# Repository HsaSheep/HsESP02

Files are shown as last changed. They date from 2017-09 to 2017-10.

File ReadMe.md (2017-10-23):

[schema](ESP-WROOM-02_BreakOut)

## About repo. ##

This repository converts "ESP-WROOM-02" module to 2.54 mm pitch.  
I am assuming to use on a solderless breadboard.

---
## Board's ##

#### V4 ####

Memo : V4はサンプル画像と作者の実物でいくつかの変更点が含まれていますが、回路な変更はありません。<br>
　　　　Sillk等にいくつかの軽微な修正が含まれています。また、それに伴いBuildDataが更新されています。

<table>
    <tr>
        <td>
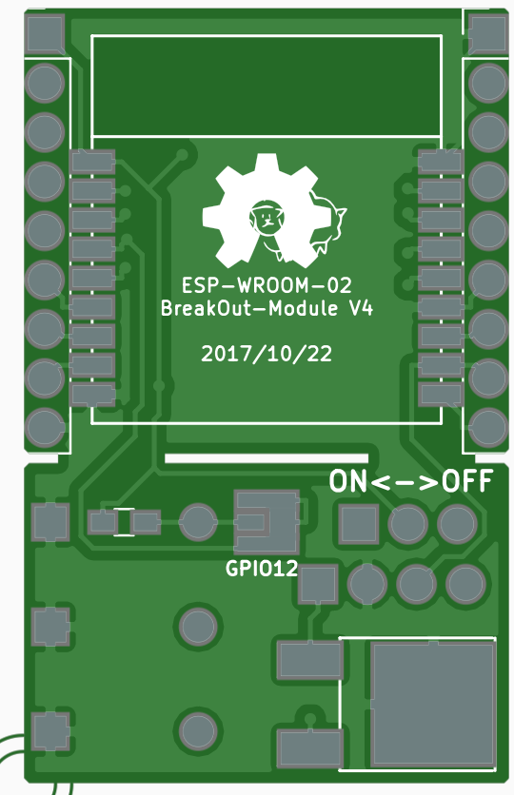
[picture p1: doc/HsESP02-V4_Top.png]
            
        </td>
        <td>
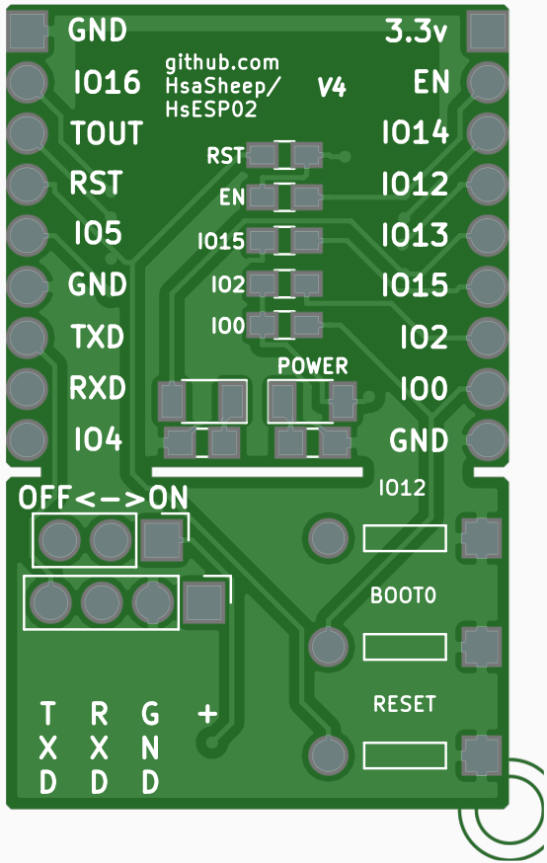
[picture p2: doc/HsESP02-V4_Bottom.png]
Bottom View(image)
            
        </td>
    </tr>
</table>

<!--
[schema]
-->

---

<details>
<summary>Old Version...</summary>

#### V3 ####

<table>
    <tr>
        <td>
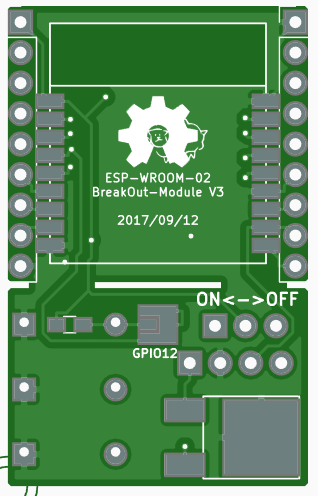
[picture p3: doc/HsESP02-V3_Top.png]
            
        </td>
        <td>
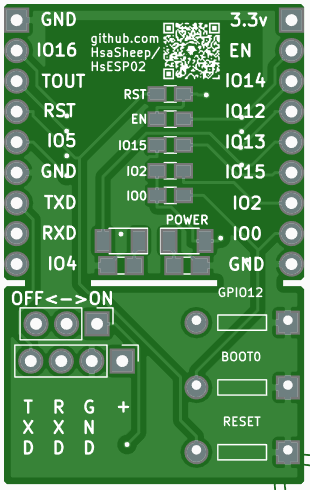
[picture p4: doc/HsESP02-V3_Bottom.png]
Bottom View(image)
            
        </td>
    </tr>
</table>

<!--
[schema]
-->

---

#### V2 ####

<table>
    <tr>
        <td>
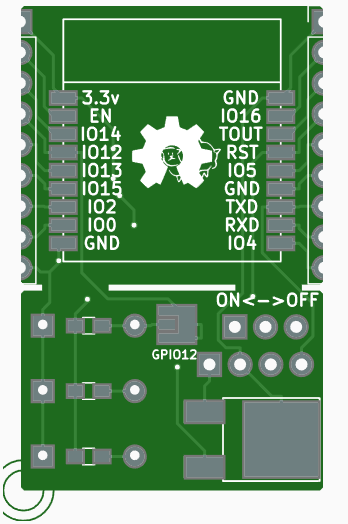
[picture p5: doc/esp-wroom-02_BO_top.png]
            
        </td>
        <td>
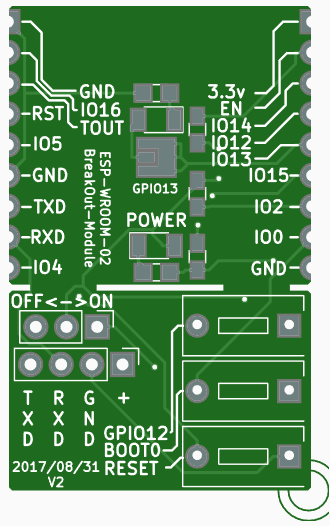
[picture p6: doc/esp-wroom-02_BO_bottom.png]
Bottom View(image)
            
        </td>
    </tr>
</table>

<!--
[schema]
-->

</details>

---

## This Repo... Empty??? ##
  
~~I am currently manufacturing the board.~~
~~All files are added as soon as normal operation can be confirmed.~~

~~(I am waiting for luggage from Elecrow.)~~

## 疲れたので日本語で追記します。 ##

Elecrowが中国の１０月の国のお休み的なやつ（国慶節）から帰ってきてくれたので
、頼んでいた基板が（かなり遅れて）到着し、現品を確認できました。

<table>
    <tr>
        <td>
            基板(右側)(image)
        </td>
        <td>
            実装した(image)
        </td>
    </tr>
</table>

難しい部分を極力省いて、比較的小型で最小限の機能のブレークアウト基板を開発することが目的でしたので、
回路的に動作しない等のエラーはありませんでした。
そもそもAutoRoutingも使ってるので、失敗する要素が少ないんですが、やっぱり不安でして。

今回の目標であった、
* Reset、Boot0 および ユーザスイッチ1個を実装する。
* 全てハード的にプルアップする(マイコンでプルアップダウンをしない)。
* ブレッドボードに直接刺せる幅で、なおかつ左右に1列ずつ余るようにする。
* 組み込んだりする際の為に、SWや書き込み端子部分を切り離せるようにする。

今回の製作で目標はとりあえず達成できたと思われるので、
設計データ等をバックアップも兼ねてアップロードして置きます。

利用は自由ですし、改変も問題ないと思います。むしろ、自分も他人様のライブラリを引っ張ってきて作っている身です。

もし、Elecrow等にガーバーぶん投げるついでに、BreakOut基板も投げたいけど作るのだるいなーって感じだった時は、一応、このデータで作れているので一緒に出すと現時点では5枚600~700円程度で作れますので割と安価だと思います。

~~もっとよくできたのが転がってそうな気がしますが…~~

ガーバーデータはKiCadフォルダ内のG_Silks_v*.zipです。基本的に数字は製作した順ですので、複数ある場合は最新を見てもらえると良いかと。
いらなくなったら最新残して消します。

一方、プロジェクトファイル自体はそのまま更新しています。内部的にはzipを弾いてGit管理しているので…。

あ、あと、世間がWiFiのセキュリティで騒いでいますね。クラックとかなんとか…
FWのアップデートがあるようなので、組み立て後にアップデートして見るのも良いかと。

その際だけはWindowsマシンがあると楽かもしれません…(実体験)

##  ファイルについて ##

* KiCad
> Kicadフォルダ内にはKiCadにて設計した基板のデータ等が入っています。

* Arduino
> Arduinoフォルダ内には基板組み立て後にLED,およびWiFi,と適当なピン(デフォルトではbeep_pinとして5ピンを指定しています)をテストするためのスケッチです。ほとんどがESP8226のHttpServerのスケッチ例そのままですが、beep_pinの名の通り、圧電スピーカを接続し、状況を音で知らせたり、MACアドレス制限(を、していて不便だったので、制限)をしている場合のためにMACアドレスを表示するようになっています。SSIDとPassWordをそれぞれ自分のWiFiものに書き換えて制作したボードに書き込み、テストしてみてください。(APとして動作するように書き換えてもいいかもしれませんね。自分はネットに接続したまま使用したいのでこのような仕様となっています。)

<details>
<summary>スケッチの使い方...</summary>

>> OTA(Over The Air 無線LAN経由によるUpdate )を使用してみたい場合
>> 1. Boot0スイッチを使用して起動しシリアル接続にてHsESP02_BasicOTA.inoを書き込んでください。
>> 1. その後、スケッチを書き込みする際にはBasicOTAに追記する形で作成し、ArduinoIDE上のシリアルポートにてネットワークポートに表示されるOTA用ポートを指定して ***Boot0スイッチ等でブートモードに入ったりはせずに*** Uploadをしてください。
>> 1. (今後はHsESP02_BasicOTA.inoやその元になっているBasicOTA.ino等にアップデートがない限り、１を実行する必要はありません。)

>> OTAを使用しない場合
>> 1. Boot0スイッチを使用して起動しシリアル接続にてHsESP02_ESP-WROOM-02_Test.inoを書き込んで動作を確認します。

</details>

##### 念のため #####
何かあっても責任はとりません。
ご自身の判断のもと行ってください。

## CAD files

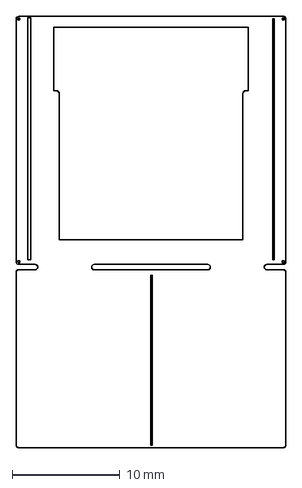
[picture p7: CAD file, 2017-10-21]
KiCad/dxf/ESP-WROOM-02_2.dxf
25.0 x 40.0 mm

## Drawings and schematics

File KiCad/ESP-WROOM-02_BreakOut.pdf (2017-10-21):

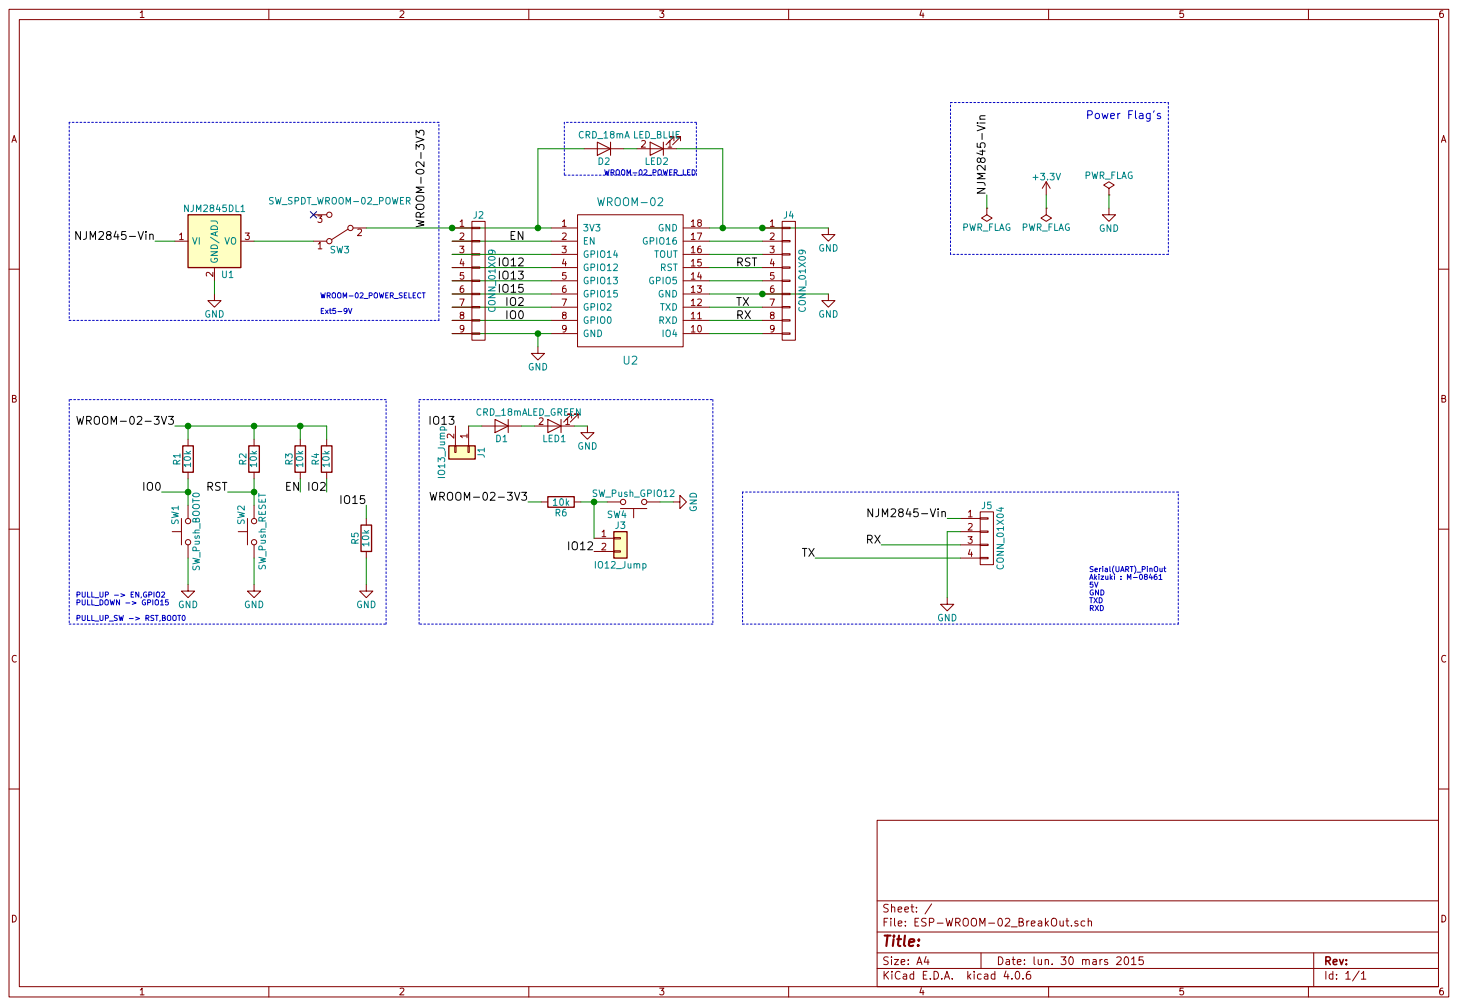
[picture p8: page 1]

File: ESP-WROOM-02_BreakOut.sch Sheet: /
Id: 1/1 Title:

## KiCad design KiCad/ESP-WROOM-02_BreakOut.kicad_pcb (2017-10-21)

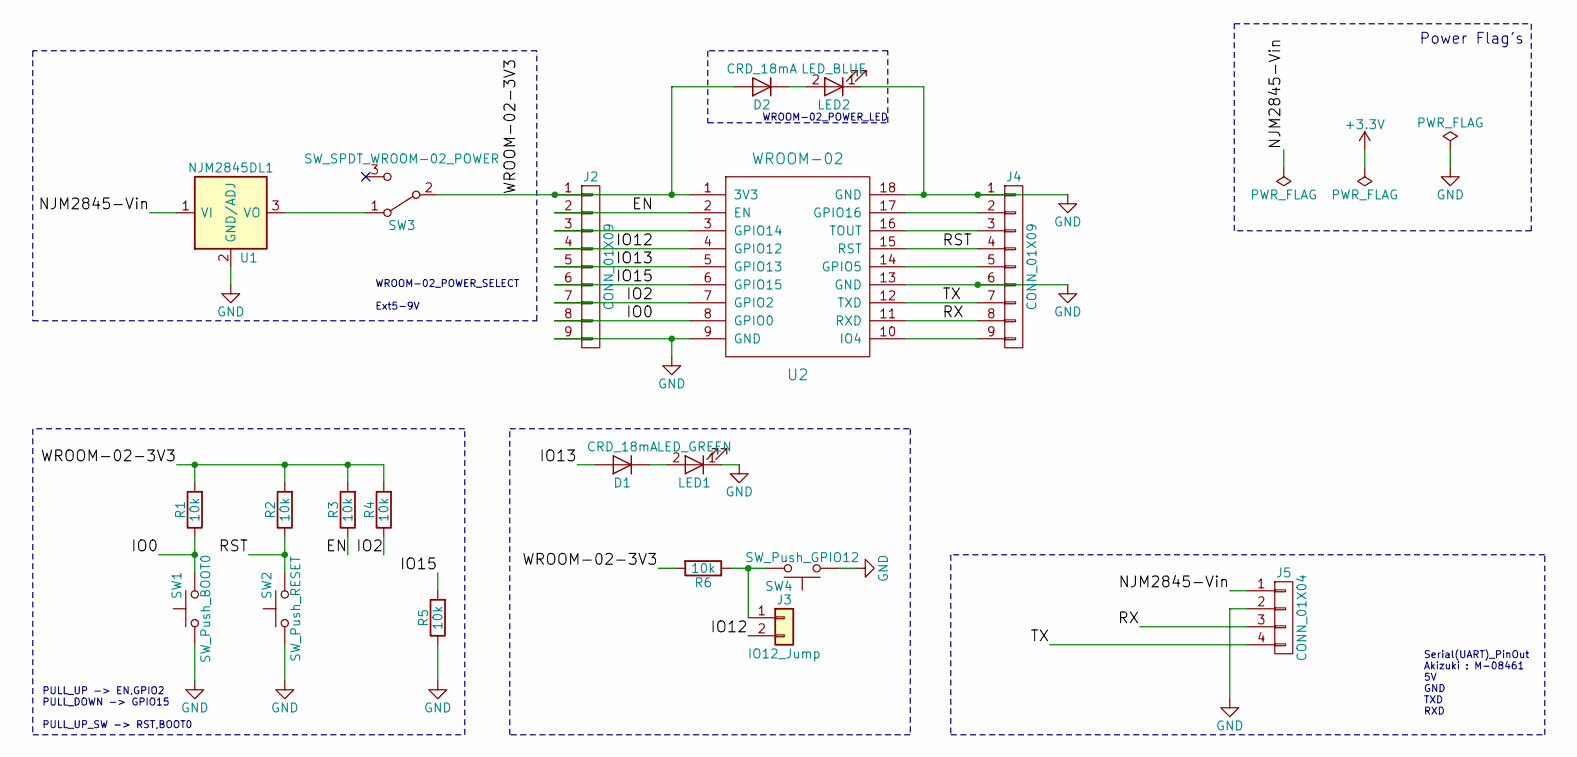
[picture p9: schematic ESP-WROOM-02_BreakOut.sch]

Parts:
D1, D2: CRD_18mA; D_1206
J2, J4: CONN_01X09; Pin_Header_Straight_1x09_Pitch2.54mm
J3: IO12_Jump; JUMPER-SOLDER-3mm
J5: CONN_01X04; Pin_Header_Straight_1x04_Pitch2.54mm
LED1: LED_GREEN; LED_0805
LED2: LED_BLUE; LED_0805
R1, R2, R3, R4, R5, R6: 10k; R_0603_HandSoldering
SW1: SW_Push_BOOT0; SW_DIP_x1_W7.62mm_Slide_MOD_TVBP06-B043C
SW2: SW_Push_RESET; SW_DIP_x1_W7.62mm_Slide_MOD_TVBP06-B043C
SW3: SW_SPDT_WROOM-02_POWER; Pin_Header_Straight_1x03_Pitch2.54mm
SW4: SW_Push_GPIO12; SW_DIP_x1_W7.62mm_Slide_MOD_TVBP06-B043C
U1: NJM2845DL1; NJM2845
U2: WROOM-02

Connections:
/EN: J2.2, R3.1, U2.2 (EN)
/IO0: J2.8, R1.1, SW1.2, U2.8 (GPIO0)
/IO2: J2.7, R4.1, U2.7 (GPIO2)
/IO12: J2.4, J3.2, U2.4 (GPIO12)
/IO13: D1.2 (A), J2.5, U2.5 (GPIO13)
/IO15: J2.6, R5.2, U2.6 (GPIO15)
/NJM2845-Vin: J5.1, U1.1 (VI)
/RST: J4.4, R2.1, SW2.2, U2.15 (RST)
/RX: J4.8, J5.3, U2.11 (RXD)
/TX: J4.7, J5.4, U2.12 (TXD)
/WROOM-02-3V3: D2.2 (A), J2.1, R1.2, R2.2, R3.2, R4.2, R6.2, SW3.2 (B), U2.1 (3V3)
GND: J2.9, J4.1, J4.6, J5.2, LED1.1 (K), LED2.1 (K), R5.1, SW1.1, SW2.1, SW4.1, U1.2 (GND/ADJ), U2.9 (GND), U2.13 (GND), U2.18 (GND)
unnamed: D1.1 (K), LED1.2 (A)
unnamed: D2.1 (K), LED2.2 (A)
unnamed: J2.3, U2.3 (GPIO14)
unnamed: J3.1, R6.1, SW4.2
unnamed: J4.2, U2.17 (GPIO16)
unnamed: J4.3, U2.16 (TOUT)
unnamed: J4.5, U2.14 (GPIO5)
unnamed: J4.9, U2.10 (IO4)
unnamed: SW3.1 (A), U1.3 (VO)

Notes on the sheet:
PULL_UP -> EN,GPIO2 PULL_DOWN -> GPIO15 PULL_UP_SW -> RST,BOOT0
Serial(UART)_PinOut Akizuki : M-08461 5V GND TXD RXD
WROOM-02_POWER_SELECT Ext5-9V
WROOM-02_POWER_LED
Power Flag's

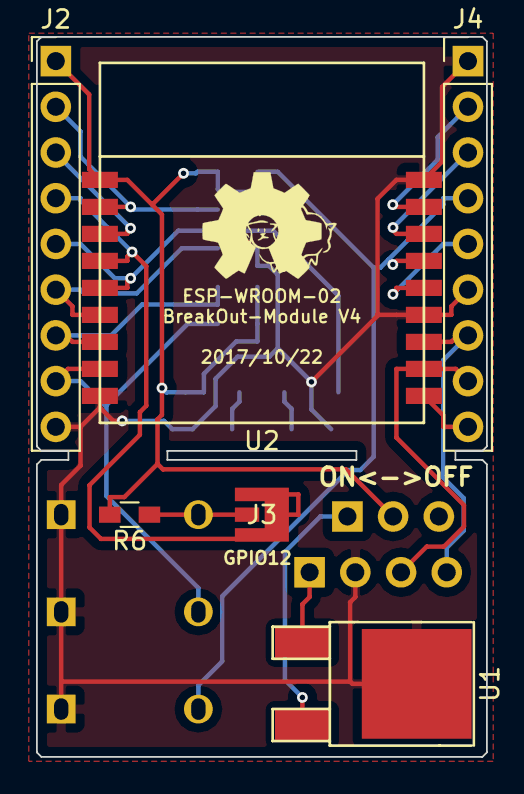
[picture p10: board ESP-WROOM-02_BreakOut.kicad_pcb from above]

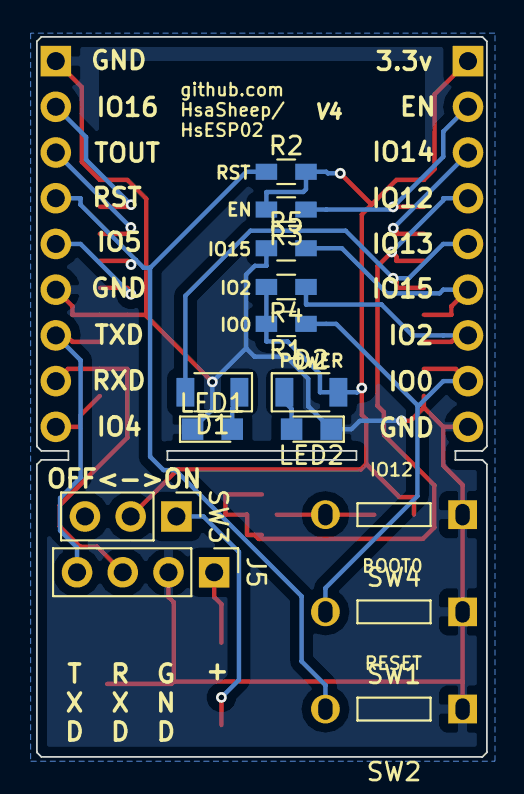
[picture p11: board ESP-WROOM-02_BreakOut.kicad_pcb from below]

Board: 2 copper layers, 25.0 x 40.0 mm, 20 parts (14 on the bottom side), 21 nets.

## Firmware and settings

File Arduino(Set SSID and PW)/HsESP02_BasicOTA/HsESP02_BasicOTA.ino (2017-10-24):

#include <ESP8266WiFi.h>
#include <ESP8266mDNS.h>
#include <WiFiUdp.h>
#include <ArduinoOTA.h>

// in ~/Arduino/librarys/***/WIFI_SETTING.h
#include <WIFI_SETTING.h>
//#define SSID_DEFINE ()
//#define WIFI_PASSWD_DEFINE ()

const char* ssid = SSID_DEFINE;
const char* password = WIFI_PASSWD_DEFINE;

const int led = 13;
const int beep_pin =  16;

void beep(unsigned char delayms,unsigned char val = 20){
  analogWrite(beep_pin, val);      // Almost any value can be used except 0 and 255
                                  // experiment to get the best tone
  delay(delayms);                 // wait for a delayms ms
  analogWrite(beep_pin, 0);       // 0 turns it off
  delay(delayms);                 // wait for a delayms ms
  digitalWrite(beep_pin, 0);
}

void setup() {
  byte mac_addr[6];
  static char buff[20];
  WiFi.macAddress(mac_addr);
  sprintf(buff, "%02X:%02X:%02X:%02X:%02X:%02X",
  mac_addr[0],
  mac_addr[1],
  mac_addr[2],
  mac_addr[3],
  mac_addr[4],
  mac_addr[5]);

  pinMode(led, OUTPUT);
  pinMode(beep_pin,OUTPUT);
  digitalWrite(led, 1);
  beep(50);
  beep(50);
  beep(50);
  Serial.begin(115200);
  Serial.println("");
  Serial.println("---- Booting... ---");
  Serial.println("----- Serial Begin -----");
  Serial.print("  Mac Addr: ");
  Serial.println(buff);
  Serial.println(" !Enable OTA(BASIC_MODE)!");
  Serial.print("Connect to ");
  Serial.println(ssid);
  WiFi.mode(WIFI_STA); // OTA
  WiFi.begin(ssid, password);
  Serial.println("----- WiFi Connect wait... -----");

  // Wait for connection
  int counter = 0;
  while (WiFi.status() != WL_CONNECTED) {
    digitalWrite(led, 1);
    delay(100);
    digitalWrite(led, 0);
    delay(100);
    digitalWrite(led, 1);
    delay(100);
    digitalWrite(led, 0);
    delay(700);
    Serial.print(".");
    counter++;
    if(counter > (60 * 5)) //5分以上経過
    {
      Serial.println("Connection Failed! Rebooting...");
      digitalWrite(led, 1);
      delay(500);
      digitalWrite(led, 0);
      delay(500);
      digitalWrite(led, 1);
      delay(500);
      ESP.restart();
    }
  }
// ---------- OTA setup's ---------- //
// Port defaults to 8266
  // ArduinoOTA.setPort(8266);

  // Hostname defaults to esp8266-[ChipID]
  ArduinoOTA.setHostname("HsESP02_v4");

  // No authentication by default
  // ArduinoOTA.setPassword((const char *)"123");

  ArduinoOTA.onStart([]() {
    Serial.println("Start");
  });
  ArduinoOTA.onEnd([]() {
    Serial.println("\nEnd");
  });
  ArduinoOTA.onProgress([](unsigned int progress, unsigned int total) {
    Serial.printf("Progress: %u%%\r", (progress / (total / 100)));
  });
  ArduinoOTA.onError([](ota_error_t error) {
    Serial.printf("Error[%u]: ", error);
    if (error == OTA_AUTH_ERROR) Serial.println("Auth Failed");
    else if (error == OTA_BEGIN_ERROR) Serial.println("Begin Failed");
    else if (error == OTA_CONNECT_ERROR) Serial.println("Connect Failed");
    else if (error == OTA_RECEIVE_ERROR) Serial.println("Receive Failed");
    else if (error == OTA_END_ERROR) Serial.println("End Failed");
  });
  ArduinoOTA.begin();
  Serial.println("");
  Serial.println("OTA Ready.");
// ------------------------------------ //

// ピン設定
  
  digitalWrite(led,1);
  Serial.println("");
  Serial.println("----- WiFi Connected! -----");
  Serial.print(" Connected: ");
  Serial.println(ssid);
  Serial.print("IP address: ");
  Serial.println(WiFi.localIP());
  beep(50);
  beep(50);
  digitalWrite(led, 0);
  Serial.println("----- !!! StartUp Done (OTA ONLY MODE) !!! -----");
}

void loop() {
  ArduinoOTA.handle(); // OTA
}

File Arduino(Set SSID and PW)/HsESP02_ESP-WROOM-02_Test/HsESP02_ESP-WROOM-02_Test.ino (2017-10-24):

/* /////////////////////////// */
/*  BeepTest And MacAddr_Send  */
/* 					            		   */
/* SSIDandPW Write and Upload  */
/* /////////////////////////// */

#include <ESP8266WiFi.h>
#include <WiFiClient.h>
#include <ESP8266WebServer.h>
#include <ESP8266mDNS.h>
#include <WiFiUdp.h>     //OTA
#include <ArduinoOTA.h>  //OTA

// in ~/Arduino/librarys/***/WIFI_SETTING.h
#include <WIFI_SETTING.h>
//#define SSID_DEFINE ()
//#define WIFI_PASSWD_DEFINE ()

const char* ssid = SSID_DEFINE;
const char* password = WIFI_PASSWD_DEFINE;

ESP8266WebServer server(80);

#define INCOMING_SIZE (5000)

const int led = 13;
const int beep_pin =  16;

void beep(unsigned char delayms,unsigned char val = 20){
  analogWrite(beep_pin, val);      // Almost any value can be used except 0 and 255
                                  // experiment to get the best tone
  delay(delayms);                 // wait for a delayms ms
  analogWrite(beep_pin, 0);       // 0 turns it off
  delay(delayms);                 // wait for a delayms ms
  digitalWrite(beep_pin, 0);
}

void tone_(unsigned int hz,unsigned int delayms = 100)
{
  tone(beep_pin, hz, delayms);
  delay(delayms);
  digitalWrite(beep_pin, 0);
}

char* mac_return(void)
{
  byte mac_addr[6];
  static char buff[20];
  WiFi.macAddress(mac_addr);
  sprintf(buff, "%02X:%02X:%02X:%02X:%02X:%02X",
  mac_addr[0],
  mac_addr[1],
  mac_addr[2],
  mac_addr[3],
  mac_addr[4],
  mac_addr[5]);
  return buff;
}

char incomingChar[INCOMING_SIZE]={};
int incomingCount = 0;

void incoming_Clear(void)
{
  for(incomingCount=0; incomingCount<INCOMING_SIZE; incomingCount++)
  {
    incomingChar[incomingCount] = 0;
  }
  incomingCount = 0;
}

void handleRoot() {
  digitalWrite(led, 1);
  if(incomingCount == 0) server.send(200, "text/html", "hello from esp8266!</br></br>No Serial Recived(Cleared)...</br>");
  else server.send(200, "text/plain", incomingChar);
  digitalWrite(led, 0);
}

void handleNotFound(){
  digitalWrite(led, 1);
  String message = "File Not Found\n\n";
  message += "URI: ";
  message += server.uri();
  message += "\nMethod: ";
  message += (server.method() == HTTP_GET)?"GET":"POST";
  message += "\nArguments: ";
  message += server.args();
  message += "\n";
  for (uint8_t i=0; i<server.args(); i++){
    message += " " + server.argName(i) + ": " + server.arg(i) + "\n";
  }
  server.send(404, "text/plain", message);
  digitalWrite(led, 0);
}

void setup(void){
  //最低限のピン設定(LED,Beep等)OTA設定後にもう一回ピン設定
  pinMode(led, OUTPUT);
  pinMode(beep_pin,OUTPUT);
  digitalWrite(led, 1);
  beep(50);
  beep(50);
  beep(50);
  Serial.begin(115200);
  Serial.println("");
  Serial.println("----- Booting... -----");
  Serial.println("----- Serial Begin -----");
  Serial.print("  Mac Addr: ");
  Serial.println(mac_return());
  Serial.println(" !Enable OTA!");
  Serial.print("Connect to ");
  Serial.println(ssid);
  WiFi.mode(WIFI_STA); // OTA
  WiFi.begin(ssid, password);
  Serial.println("----- WiFi Connect wait... -----");

  // Wait for connection
  int counter = 0;
  while (WiFi.status() != WL_CONNECTED) {
    digitalWrite(led, 1);
    delay(100);
    digitalWrite(led, 0);
    delay(100);
    digitalWrite(led, 1);
    delay(100);
    digitalWrite(led, 0);
    delay(700);
    Serial.print(".");
    counter++;
    if(counter > (60 * 5)) //5分以上経過
    {
      Serial.println("Connection Failed! Rebooting...");
      digitalWrite(led,1);
      delay(500);
      digitalWrite(led,0);
      delay(500);
      digitalWrite(led,1);
      delay(500);
      ESP.restart();
    }
  }
// ---------- OTA setup's ---------- //
// Port defaults to 8266
  // ArduinoOTA.setPort(8266);

  // Hostname defaults to esp8266-[ChipID]
  ArduinoOTA.setHostname("HsESP02_v4");

  // No authentication by default
  // ArduinoOTA.setPassword((const char *)"123");

  ArduinoOTA.onStart([]() {
    Serial.println("Start");
  });
  ArduinoOTA.onEnd([]() {
    Serial.println("\nEnd");
  });
  ArduinoOTA.onProgress([](unsigned int progress, unsigned int total) {
    Serial.printf("Progress: %u%%\r", (progress / (total / 100)));
  });
  ArduinoOTA.onError([](ota_error_t error) {
    Serial.printf("Error[%u]: ", error);
    if (error == OTA_AUTH_ERROR) Serial.println("Auth Failed");
    else if (error == OTA_BEGIN_ERROR) Serial.println("Begin Failed");
    else if (error == OTA_CONNECT_ERROR) Serial.println("Connect Failed");
    else if (error == OTA_RECEIVE_ERROR) Serial.println("Receive Failed");
    else if (error == OTA_END_ERROR) Serial.println("End Failed");
  });
  ArduinoOTA.begin();
  Serial.println("");
  Serial.println("OTA Ready.");
// ------------------------------------ //

// ピン設定
  //i2c  SDA:IO4 SCL:IO14
  Wire.begin(4, 14);
  delay(40);

  // MPU6050 SETTING
  uint8_t cmd_init[] = {0x38, 0x39, 0x14, 0x70, 0x56, 0x6c, 0x38, 0x0d, 0x01};
  command(cmd_init, sizeof(cmd_init));
  delayMicroseconds(1080);  // 1.08ms

  uint8_t cmd_str1[] = {0x48, 0x65, 0x6c, 0x6c, 0x6f};
  uint8_t cmd_cr[] = {0xc0};
  uint8_t cmd_str2[] = {0x57, 0x6f, 0x72, 0x6c, 0x64, 0x21};
  write(cmd_str1, sizeof(cmd_str1));
  command(cmd_cr, sizeof(cmd_cr));
  write(cmd_str2, sizeof(cmd_str2));
  // MPU6050 SETTING END
  
  digitalWrite(led,1);
  Serial.println("----- WiFi Connected! -----");
  Serial.print(" Connected: ");
  Serial.println(ssid);
  Serial.print("IP address: ");
  Serial.println(WiFi.localIP());
  Serial.println("---------------------------");
  tone_(262,500);
  tone_(523,500);

  // Begin mDNS
  if (MDNS.begin("esp8266")) {
    Serial.println("MDNS responder started");
  }

  // Server On
  server.on("/", handleRoot);

  server.on("/inline", [](){
    server.send(200, "text/plain", "this works as well");
  });

  server.onNotFound(handleNotFound);

  server.on("/serial", [](){

    server.send(200, "text/plain", incomingChar);
    // 「/」に転送
    //server.sendHeader("Location", String("/"), true);
    //server.send(302, "text/plain", "");

    Serial.println("----- incomingChar -----");
    for(int i=0;i<incomingCount;i++)
    {
      if((incomingChar[i] == 0x0A) || (incomingChar[i]) == 0x0D)
       Serial.println("");
      else
        Serial.print(incomingChar[i]);
    }
    Serial.println("");
    Serial.println("----- incomingByte -----");
    for(int i=0;i<incomingCount;i++)
    {
        Serial.print("[0x");
        Serial.print((byte)(incomingChar[i]));
        Serial.print("]");
    }
    Serial.println("");
    Serial.println("----- incoming Print END -----");
  });

  server.begin();
  Serial.println("HTTP server started");
  tone_(2093,500);
  tone_(4186,500);
  digitalWrite(led, 0);
  Serial.println("----- !!! StartUp Done !!! -----");
}
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

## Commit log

2017-10-21 Update Readme.md and add ./KiCaD , ./Arduino(Set SSID and PW)
    [ESP-WROOM-02_2.dxf, ESP-WROOM-02_BreakOut.kicad_pcb, ESP-WROOM-02_BreakOut.sch]
2017-10-21 rename *.PNG -> *.png (怒
2017-10-21 doc/:変更
2017-10-21 画像サイズ調整
2017-10-21 画像サイズ調整2
2017-10-21 Readme.md 画像サイズ 今日のところは最終更新(予定)
2017-10-22 OTA用.ino追加とそれに伴うReadMe.mdの追記
2017-10-22 Serialをrootで表示する機能とかテスト用に実装
2017-10-23 テストプログラムアップデート
2017-10-23 とりあえず使えるものをコミット。Rootはシリアル受信したものをテキストとして素で吐き出します。
2017-10-23 WIFI_SETTING.hに両方とも統一
2017-10-23 WiFiの宣言周りの変更
2017-10-24 .ino内のincludeを変更
